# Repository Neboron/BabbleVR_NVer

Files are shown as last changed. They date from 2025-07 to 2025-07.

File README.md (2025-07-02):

# Face Tracker Hardware Design 

An open-source hardware project for building compact face tracker based on [Babble Project](https://babble.diy/).

## 🔧 Overview

Electronics design made with Altium Designer, including schematics, layout, and manufacturing files (Gerbers, CPL, BOM). Mechanical parts designed in SolidWorks.

## 📦 Features

- Modular and compact design
- Increased power efficiency
- Could be used both in wireless and USB mode

## 🖼️ Gallery

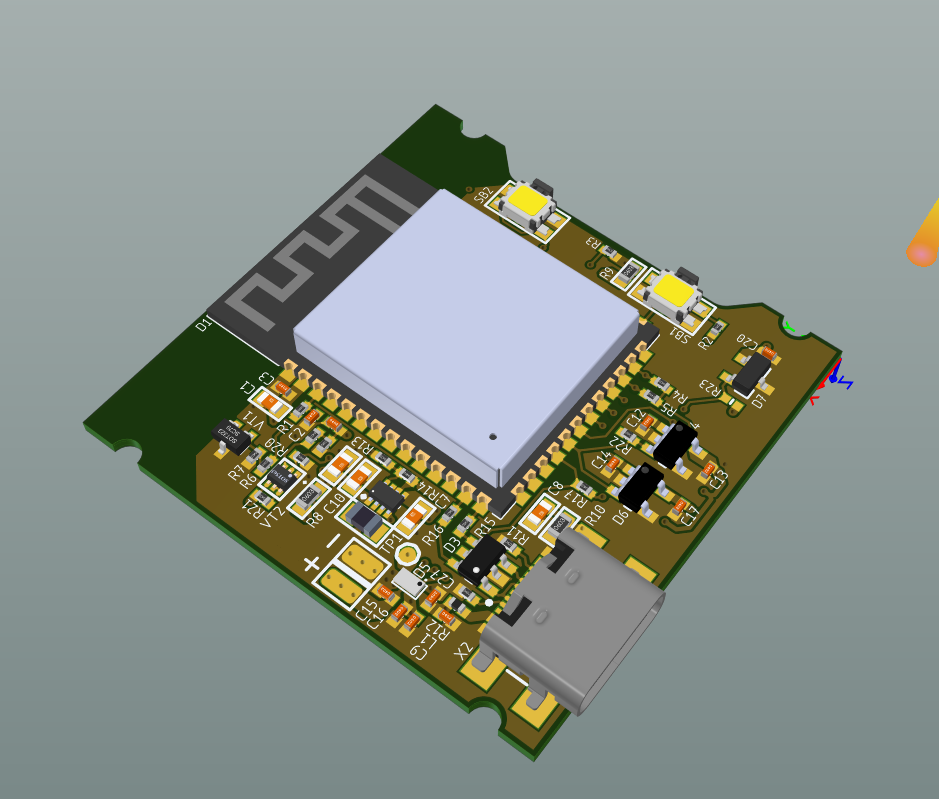
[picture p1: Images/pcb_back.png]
PCB Back

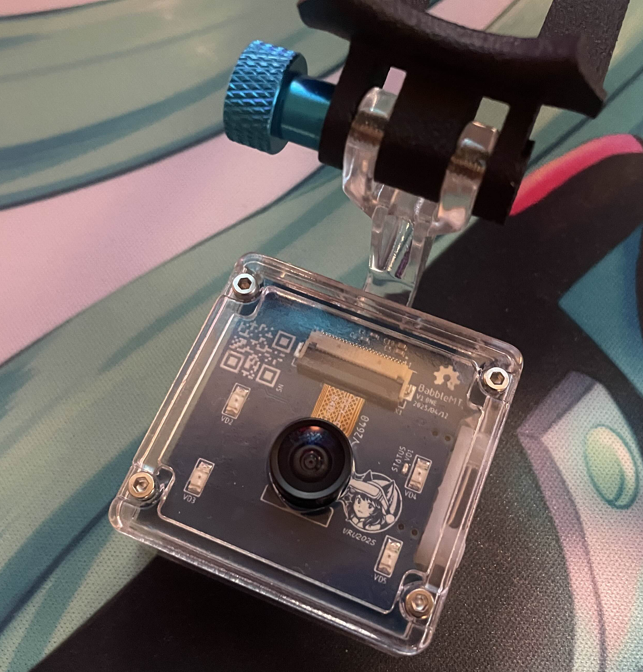
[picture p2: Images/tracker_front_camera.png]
Assembled Unit

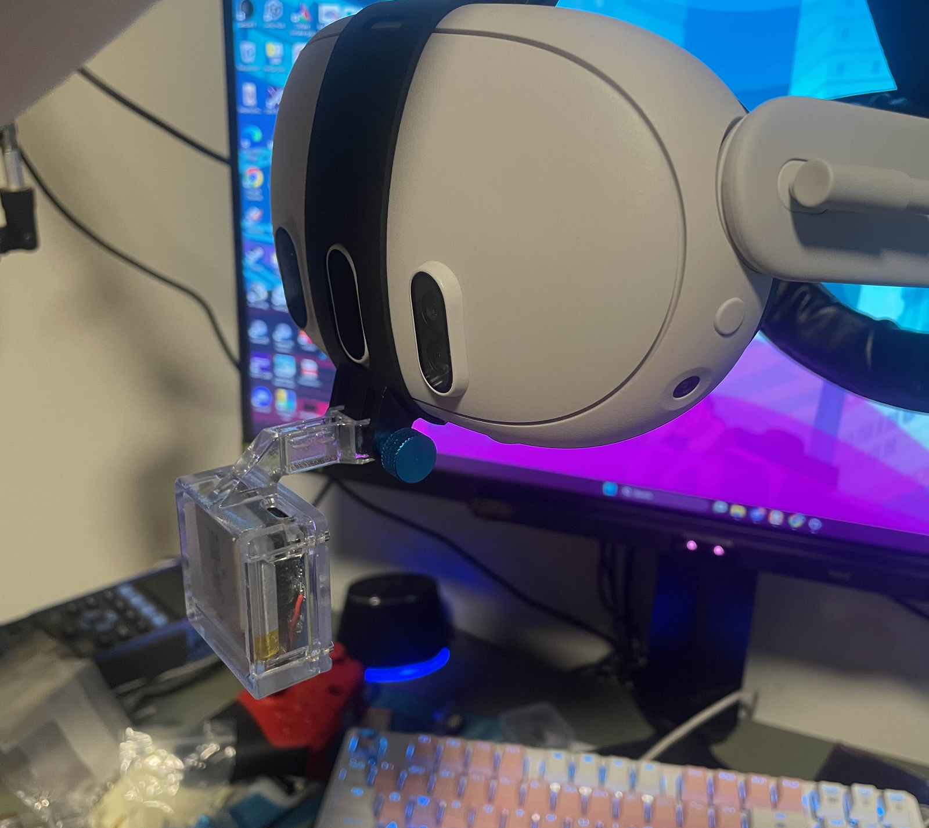
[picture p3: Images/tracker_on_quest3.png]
Tracker on Quest 3


Assembly guides will be added soon...

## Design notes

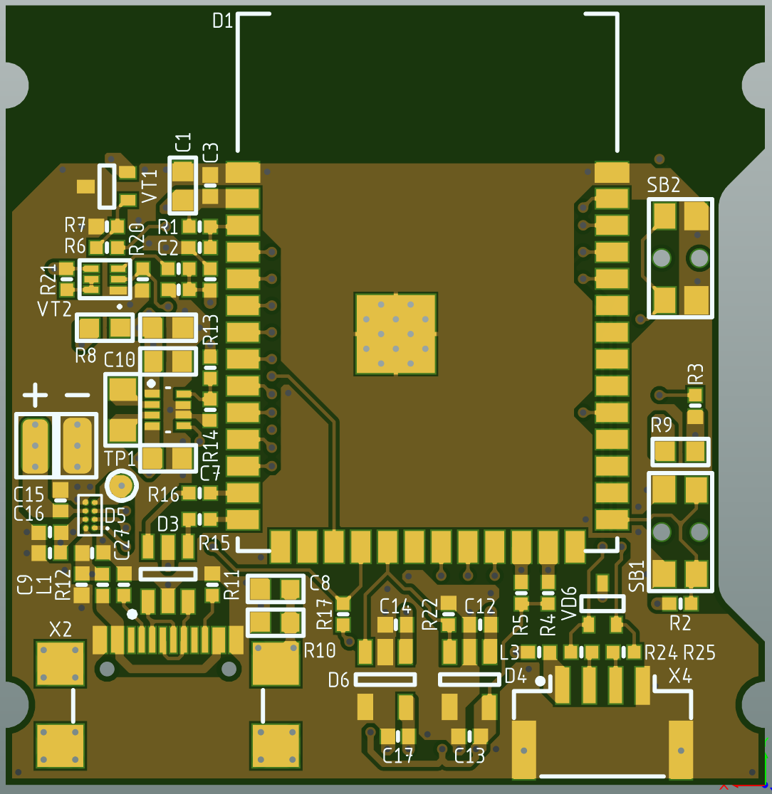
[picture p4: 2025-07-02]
Mechanical/Design/PCB/BottomSide2.png

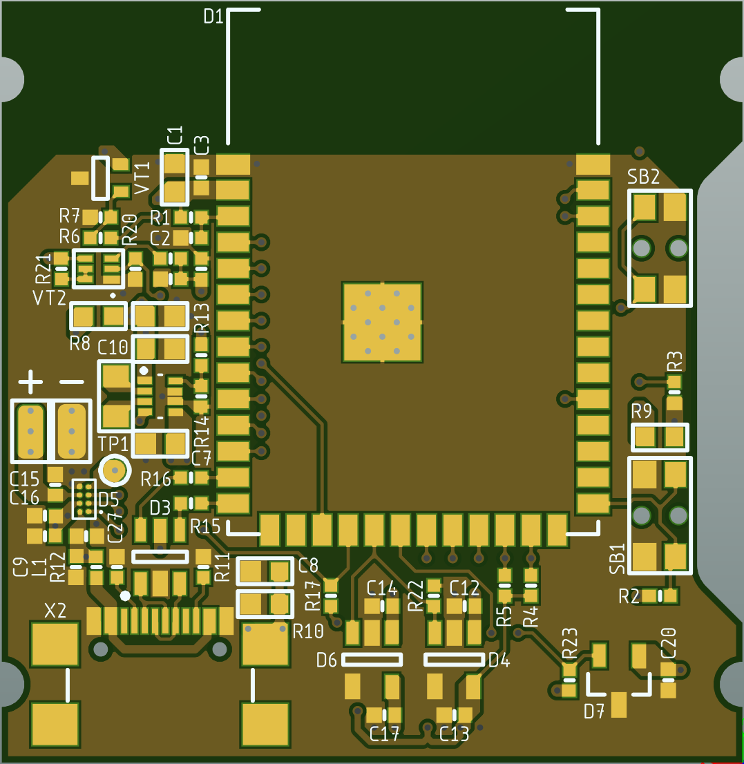
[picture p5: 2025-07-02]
Mechanical/Design/PCB/BottomSide.png

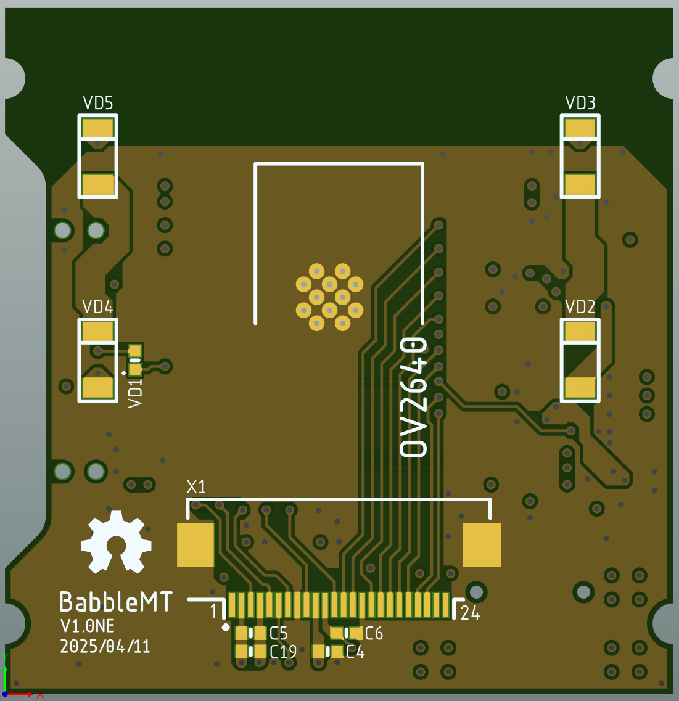
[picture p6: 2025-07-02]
Mechanical/Design/PCB/TopSide2.png

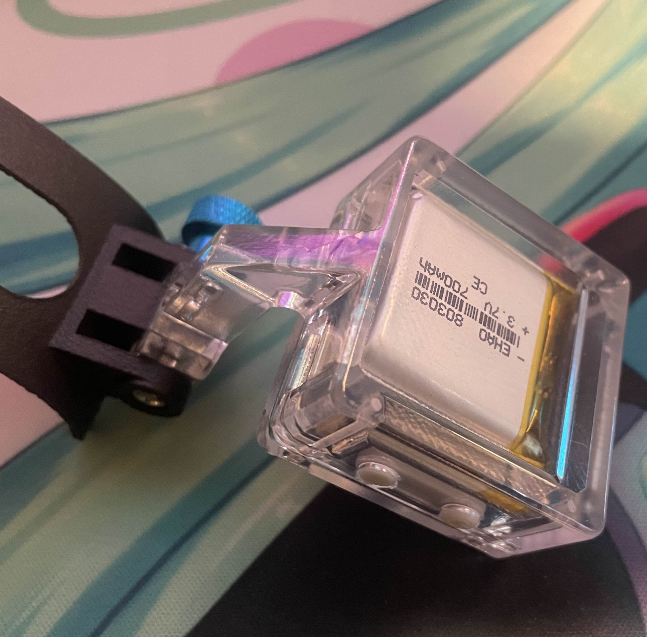
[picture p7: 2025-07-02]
Images/tracker_back.jpg

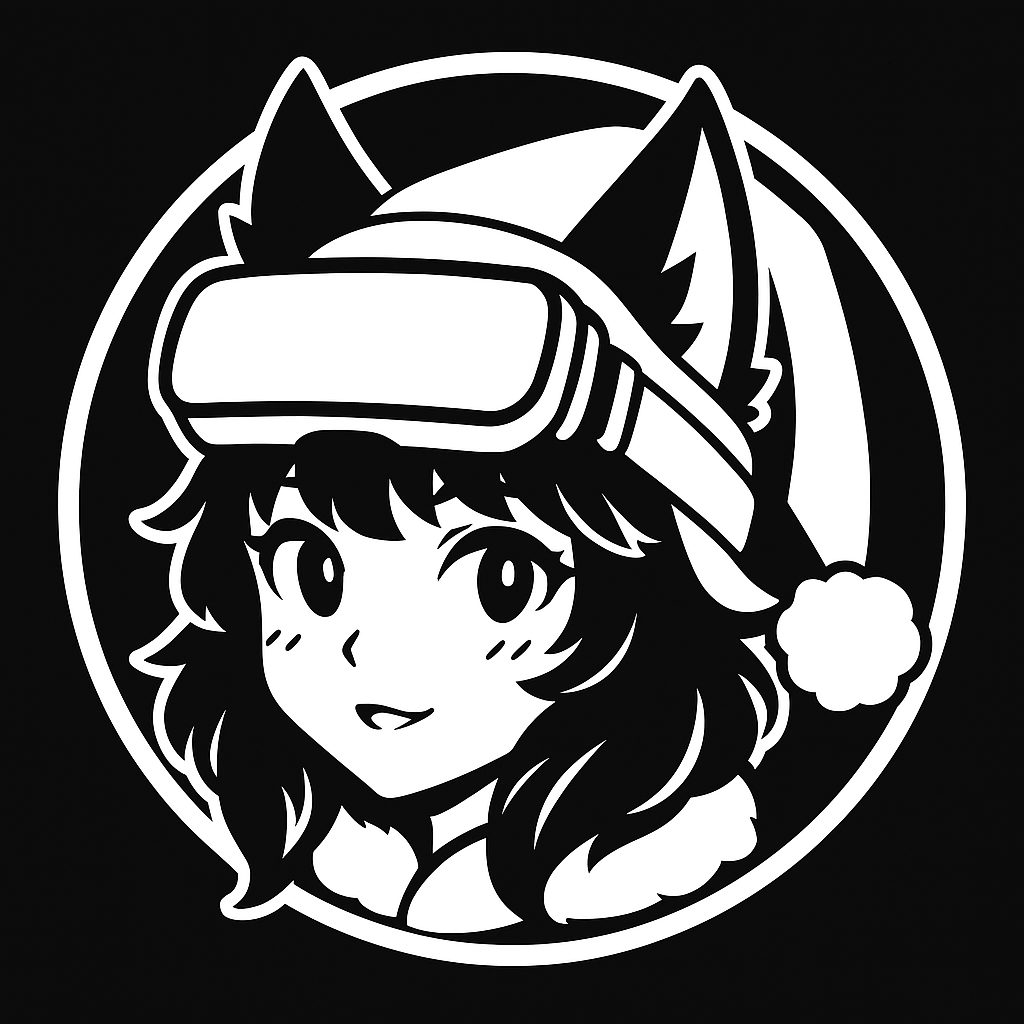
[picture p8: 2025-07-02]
PCB/Images/VRUkraine.png

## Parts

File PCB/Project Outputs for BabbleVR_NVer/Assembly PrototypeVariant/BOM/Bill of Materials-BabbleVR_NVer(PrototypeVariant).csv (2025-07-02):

Comment | Description | Designator | Footprint | LibRef | Quantity | PartNumber
Ceramic capacitor, 22uF, X5R, ±10%, 6.3V, 0603, -55...+125°C |  | C1, C7, C10, C11 | CAP: 0603 | Ceramic_0603 | 4
Ceramic capacitor, 1uF, X7R, ±10%, 6.3V, 0402, -55...+125°C |  | C2 | CAP: 0402 | Ceramic_0402 | 1
Ceramic capacitor, 100nF, X7R, ±10%, 16V, 0402, -55...+125°C |  | C3, C9, C18 | CAP: 0402 | Ceramic_0402 | 3
Ceramic capacitor, 4.7uF, X7R, ±10%, 16V, 0402, -55...+125°C |  | C4, C5, C6, C19 | CAP: 0402 | Ceramic_0402 | 4
Ceramic capacitor, 0.1uF, X7R, ±10%, 16V, 0603, -55...+125°C |  | C8 | CAP: 0603 | Ceramic_0603 | 1
Ceramic capacitor, 1uF, X7R, ±10%, 16V, 0402, -55...+125°C |  | C12, C13, C14, C15, C16, C17, C27, C33 | CAP: 0402 | Ceramic_0402 | 8
Wi-Fi module, WiFi 802.11 b/g/n (802.11n up to 150 Mbps) / Bluetooth v4.2 BR/EDR and BLE specification, 32 bit, SD card, UART, SPI, SDIO, I2C, LED PWM, Motor PWM, I2S, IR, pulse counter, GPIO, capacitive touch sensor, ADC, DAC, -40...+85°C, 18x25.5x3.1 | Wi-Fi | D1 | MOD: ESP32-S3-WROOM-1 | ESP32-S3-WROOM-1-N8R8 | 1 | ESP32-S3-WROOM-1-N8R8
DC/DC buck-boost converter, 1.6...5.5V, 2.4MHz, 1.2...5.3V, 1.5A, -40...+125°C, SOT-583 | Buck-boost converter | D2 | SOT583-8 | TPS631000DRLR | 1 | TPS631000DRLR
ESD protection, , 8kV, , -40...+125°C, SOT23-6L | ESD protection | D3 | SOT23-6 | USBLC6-2 | 1 | USBLC6-2
Linear voltage regulator, 2.9...6V, 0.5V, 1.5V, 0.25A, -40...+85°C, SOT23-5 | Linear voltage regulator 2.8V | D4 | SOT23-5 | AP2139AK-2.8TRG1 | 1 | AP2139AK-2.8TRG1
Charger li-ion battery, input 4.35...26V, , 1A, -40...+125°C, 8-DSBGA | Charger | D5 | 8-DSBGA | BQ25180YBGR | 1 | BQ25180YBGR
Linear voltage regulator, 2...5.5V, 0.26V, 1.2V, 0.3A, -40...+85°C, SOT23-5 | Linear voltage regulator 1.2V | D6 | SOT23-5 | TLV70212DBVR | 1 | TLV70212DBVR
Fixed inductor, BEAD, ±25%, 0402, 900mA, -55...+125°C |  | L1, L3 | IND: 0402 | Inductor_0402 | 2 | BLM15PX601SN1D
Fixed inductor, 1µH, ±20%, 0805, 2.2A, -55...+125°C |  | L2 | IND: 0805 | Inductor_0805 | 1 | MAKK2016T1R0M
Resistor film, 10k, ±5%, 0402, 0.063W, -55...+125°C |  | R1, R2, R4, R5, R7, R17, R19, R22 | RES: 0402 | Resistor_0402 | 8
Resistor film, 470R, ±5%, 0402, 0.063W, -55...+125°C |  | R3, R24, R25 | RES: 0402 | Resistor_0402 | 3 | RC0402JR-07100RL
Resistor film, 22R, ±5%, 0402, 0.063W, -55...+125°C |  | R6, R15, R16 | RES: 0402 | Resistor_0402 | 3
Resistor film, 9.1R, ±5%, 0603, 0.1W, -55...+125°C |  | R8, R9 | RES: 0603 | Resistor_0603 | 2
Resistor film, 330R, ±5%, 0603, 0.1W, -55...+125°C |  | R10 | RES: 0603 | Resistor_0603 | 1
Resistor film, 5.1k, ±5%, 0402, 0.063W, -55...+125°C |  | R11, R12, R18 | RES: 0402 | Resistor_0402 | 3
Resistor film, 510k, ±5%, 0402, 0.063W, -55...+125°C |  | R13, R20, R21 | RES: 0402 | Resistor_0402 | 3
Resistor film, 91k, ±5%, 0402, 0.063W, -55...+125°C |  | R14 | RES: 0402 | Resistor_0402 | 1
Tactile button, TS-1186F |  | SB1, SB2 | BUT: TS-1186F-B-A | Button_tactile | 2 | TS-1186F-C-A
Test point, Keystone, 5001 |  | TP1 | CON: TEST POINT 1 MM | Connector_Test_Point | 1 | 5001
LED, Green, *, *, *, -55...+150°C |  | VD1 | LED: 0402R | LED_single | 1
LED, 850...858nm, 35mA, 1.5V, 1206, -55...+150°C |  | VD2, VD3, VD4, VD5 | LED: 1206R | LED_single | 4 | XL-3216HIRC-850
TVS, 5.5V, 2A, , , SC-70-3, -55...+150°C |  | VD6 | SC-70 | TVS_array | 1 | SP1001-02JTG
MOSFET N-channel transistor, 60V, 380mA, , 300mW, 2.3Ohm, 34pF, SC-70, -55...+150°C |  | VT1 | SC-70 | MOSFET_N_123 | 1 | L2N7002KWT1G
MOSFET Dula-channel transistor, 20V, 700mA, N-70pC, P-850pC, 1W, N-480mOhm, P-970mOhm, N-750pF, P-1000pF, SOT563, -55...+150°C |  | VT2 | SOT563-6 | MOSFET_DUAL_NP_ISO | 1 | DMC2400UV
Connector, 24pin, 0.5mm, FFC/FPC, 0.5A |  | X1 | CON: FFC/FPC-24-0.5(Hirose) | Connector_FFC_24 (TF31-24S-0.5SH(800)) | 1 | TF31-24S-0.5SH(800)
USB Type C, 5A |  | X2 | CON: TYPE-C-SOFNG MC-311S | Connector_USB_Type_C | 1 | TYPEC-304YSSW-ACP16
Connector, 2pin, 2mm, , |  | X3 | CON: BAT (2.00) | Connector_BAT-2 | 1
Connector, 4pin, 1.25mm, 50VDC, 1A |  | X4 | CON: SM04B-GHS | Connector_SM04B | 1 | SM04B-GHS

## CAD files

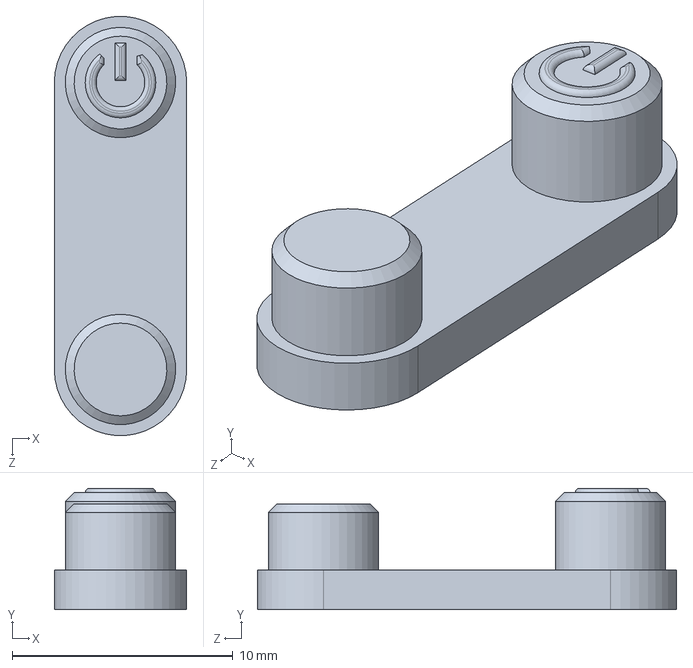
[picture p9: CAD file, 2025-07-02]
Mechanical/Design/ButtonCover_01.SLDPRT
6.00 x 5.50 x 19.0 mm

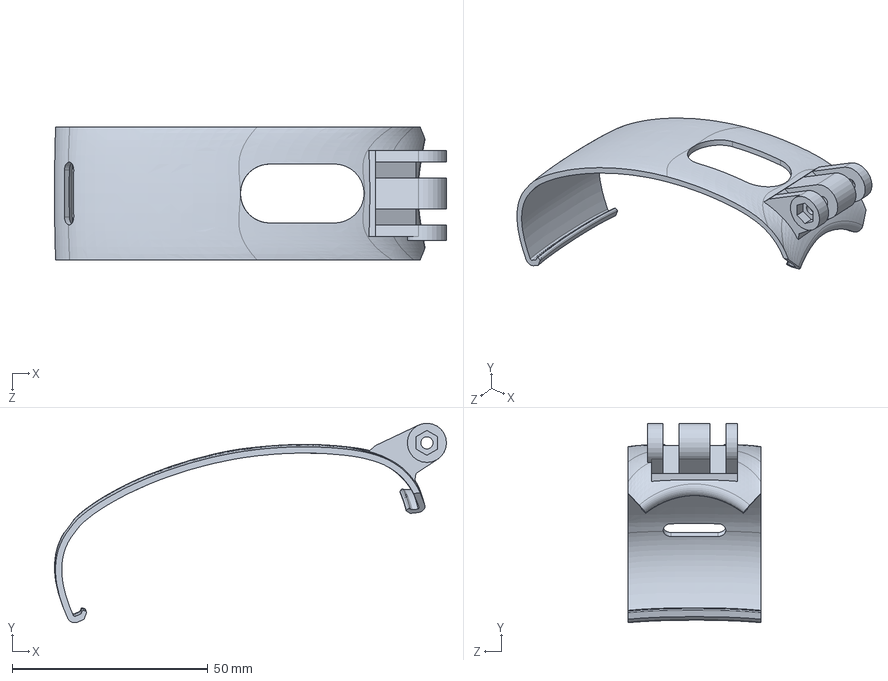
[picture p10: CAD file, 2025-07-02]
Mechanical/Design/Quest3/Quest3_MountScobe.SLDPRT
100.0 x 50.9 x 34.0 mm

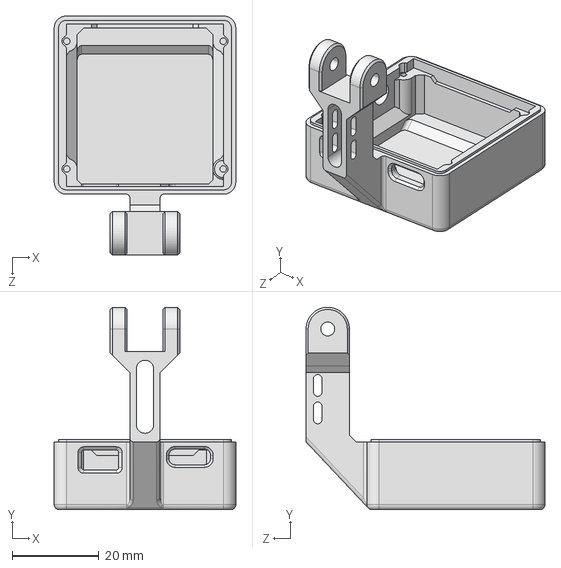
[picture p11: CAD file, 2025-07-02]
Mechanical/FabricationOutputs/STEP/CaseBottom_01.STEP
41.8 x 46.6 x 55.0 mm

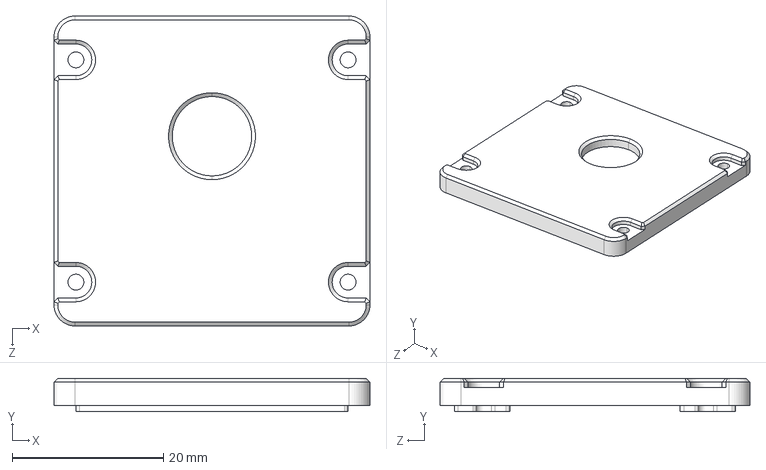
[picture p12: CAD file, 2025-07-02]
Mechanical/FabricationOutputs/STEP/CaseTop_01.STEP
41.8 x 4.40 x 41.0 mm

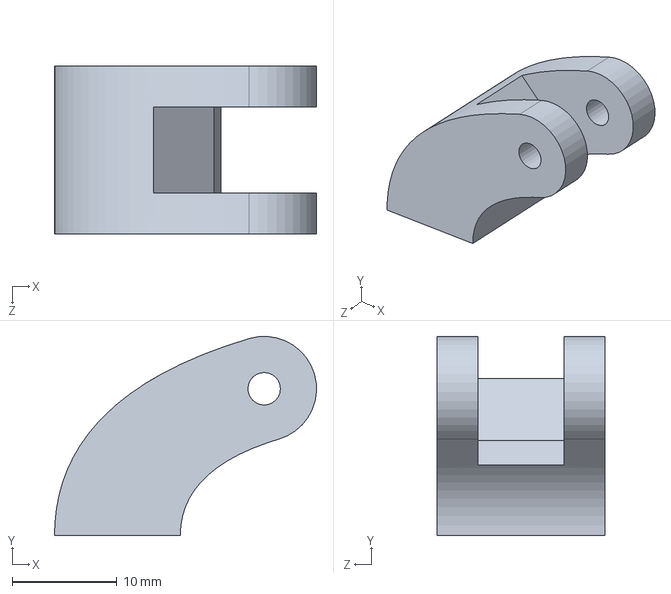
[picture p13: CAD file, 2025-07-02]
Mechanical/Design/TrackerHinge_01.SLDPRT
25.0 x 19.0 x 16.0 mm

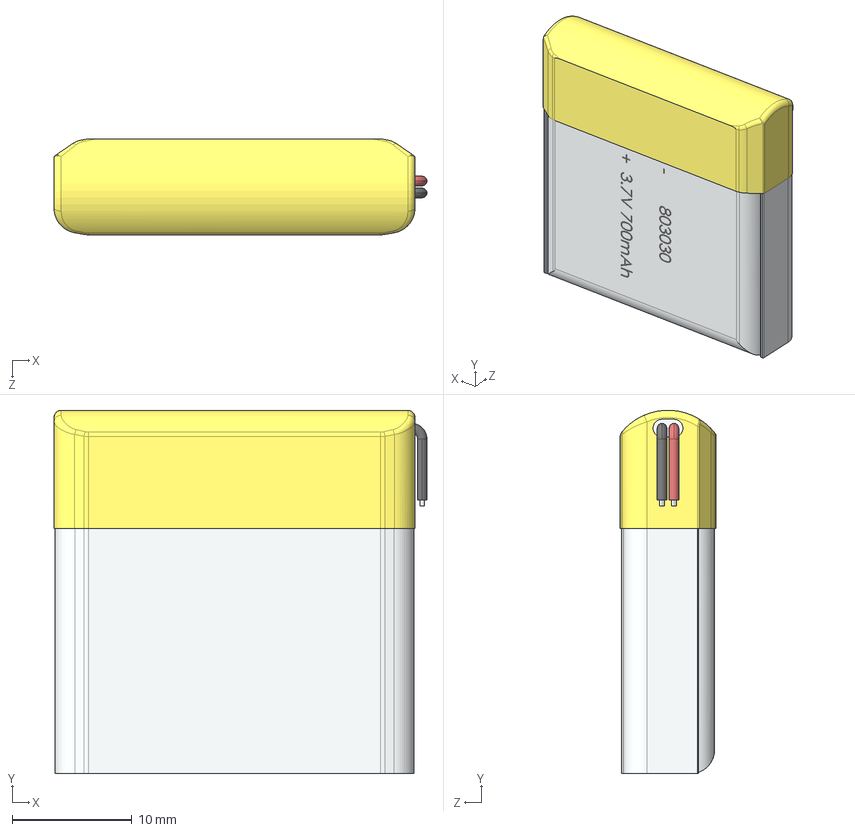
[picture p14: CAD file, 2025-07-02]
Mechanical/Design/Battery/803030.STEP
31.2 x 30.4 x 8.00 mm

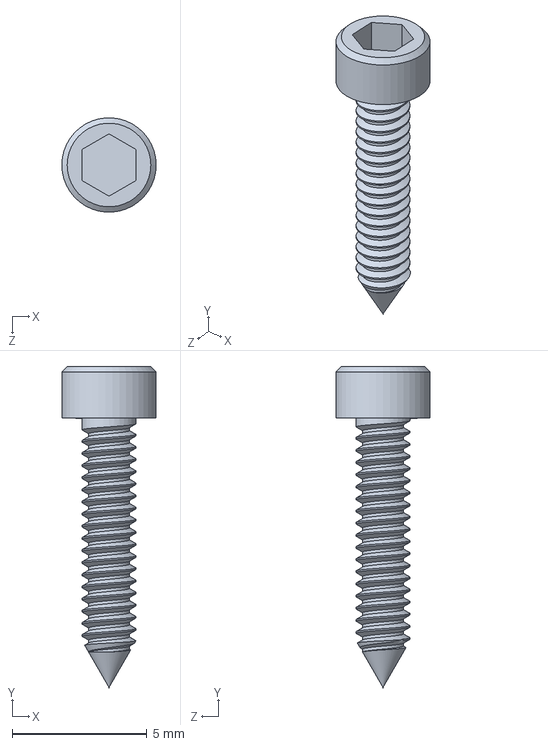
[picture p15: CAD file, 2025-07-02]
Mechanical/Design/M2_SelfTappingScrew.SLDPRT
3.50 x 11.9 x 3.49 mm

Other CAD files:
Mechanical/Design/CaseBottom_01.SLDPRT
Mechanical/FabricationOutputs/STEP/Quest3_MountScobe_01.STEP
Mechanical/Design/CaseTop_01.SLDPRT
Mechanical/FabricationOutputs/STEP/ButtonCover_01.STEP
Mechanical/Design/Battery/803030.SLDPRT

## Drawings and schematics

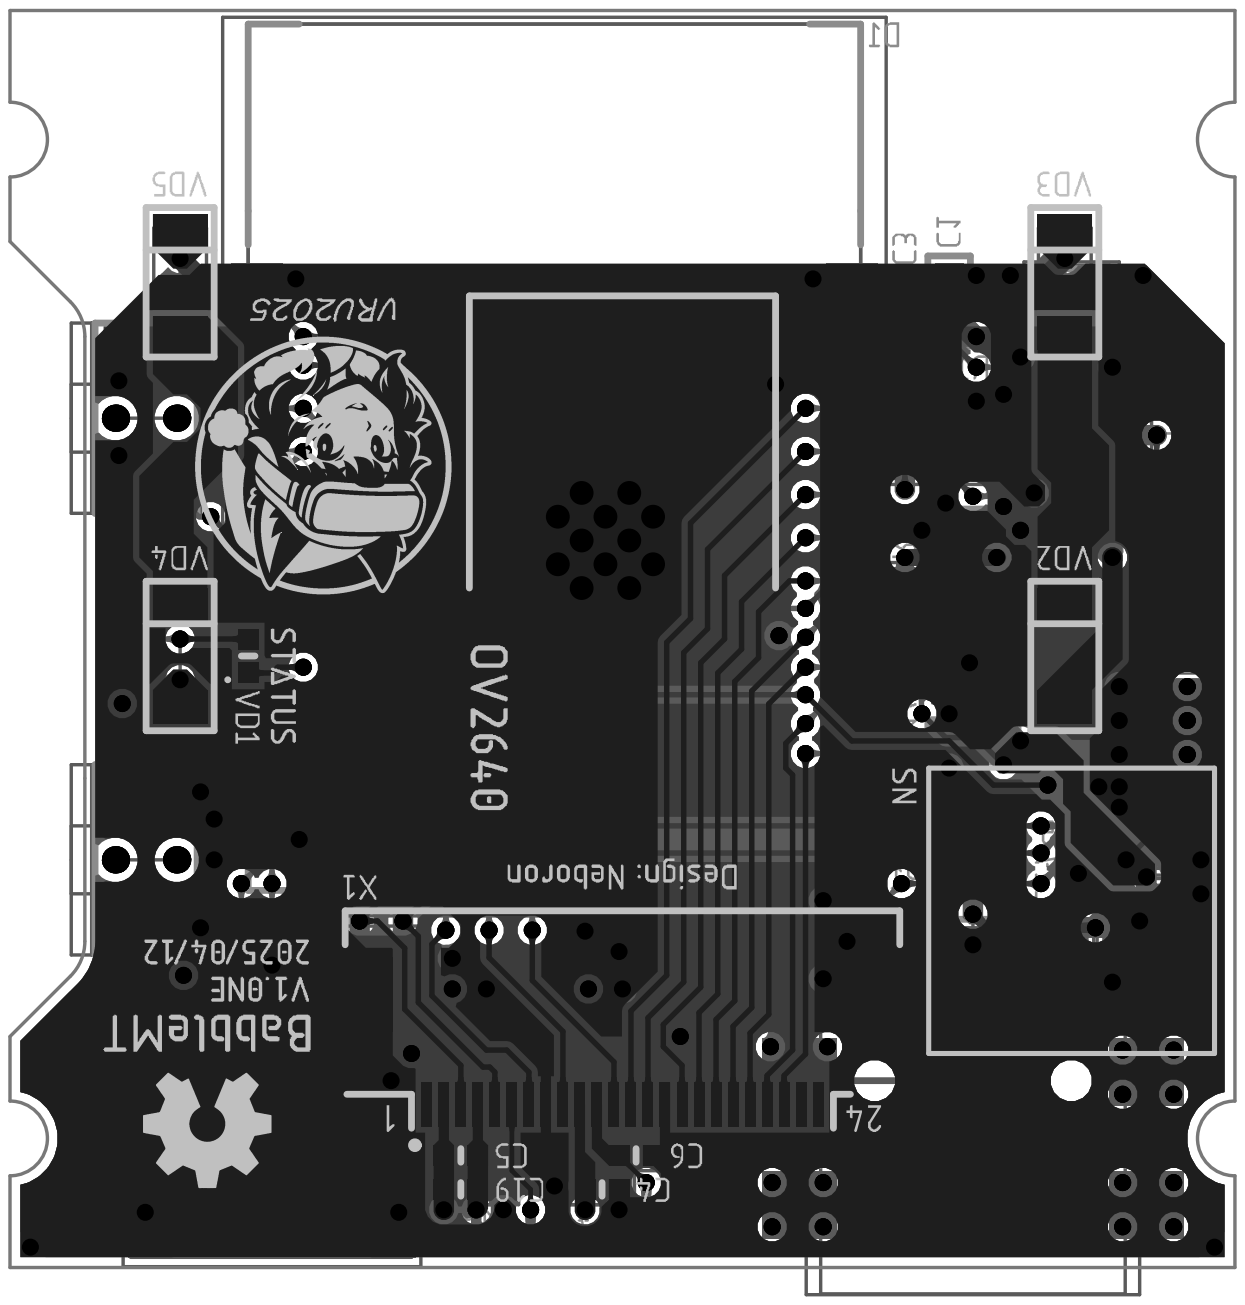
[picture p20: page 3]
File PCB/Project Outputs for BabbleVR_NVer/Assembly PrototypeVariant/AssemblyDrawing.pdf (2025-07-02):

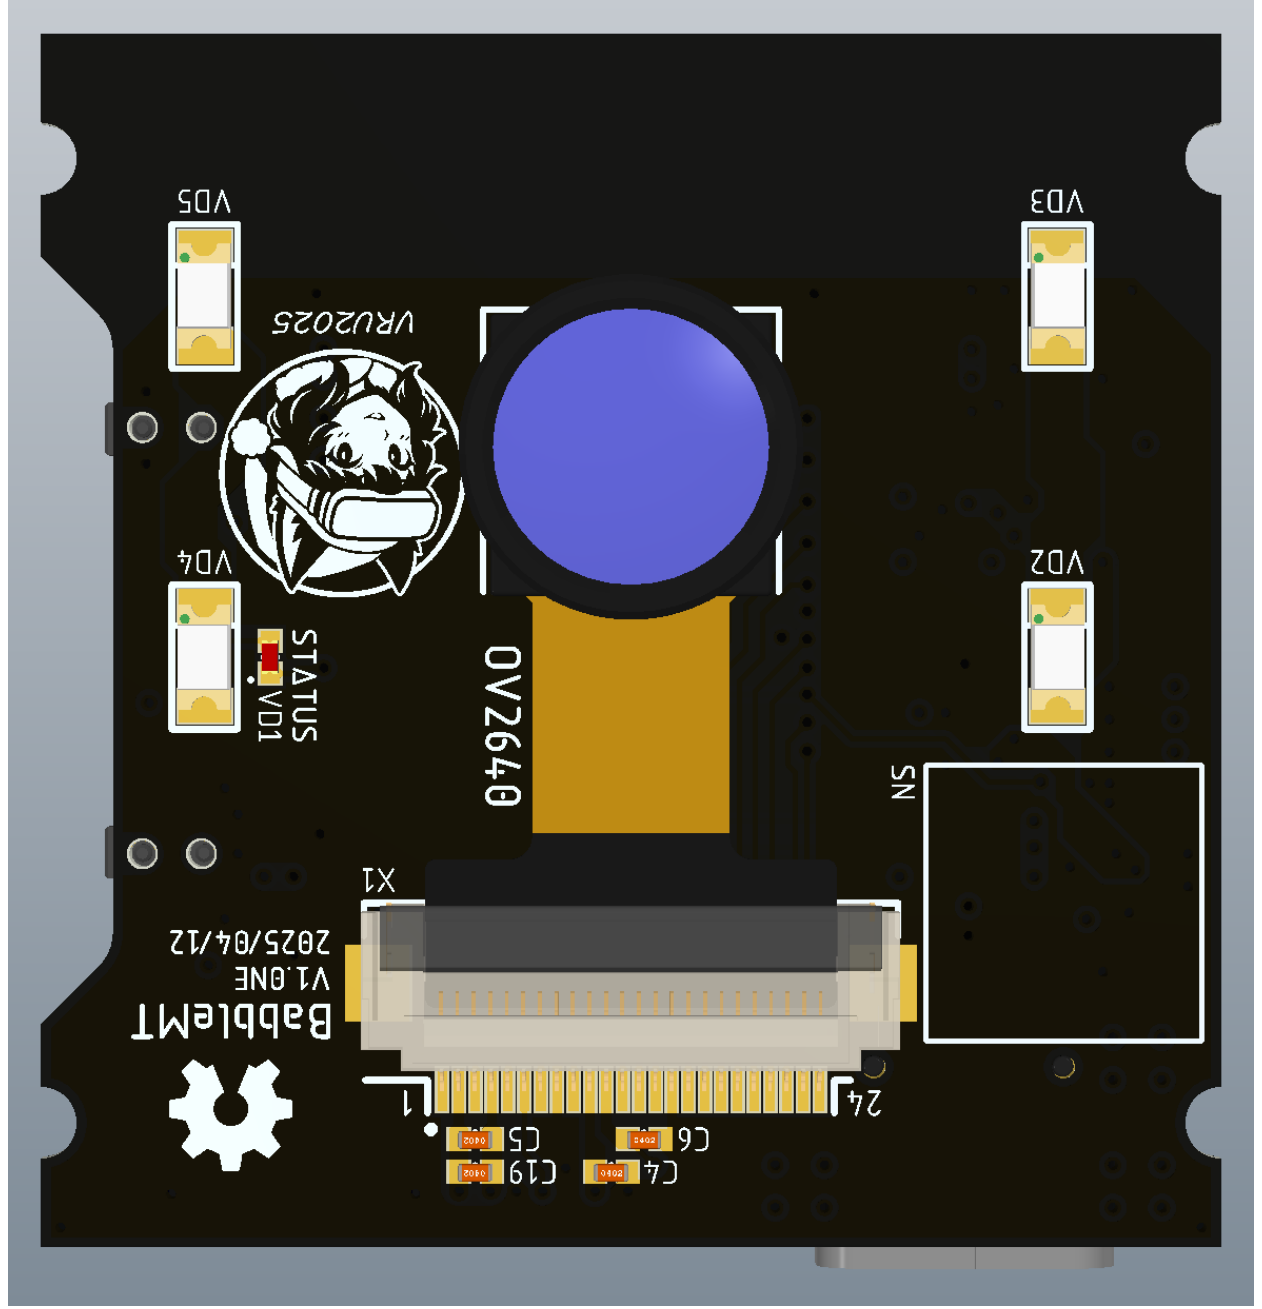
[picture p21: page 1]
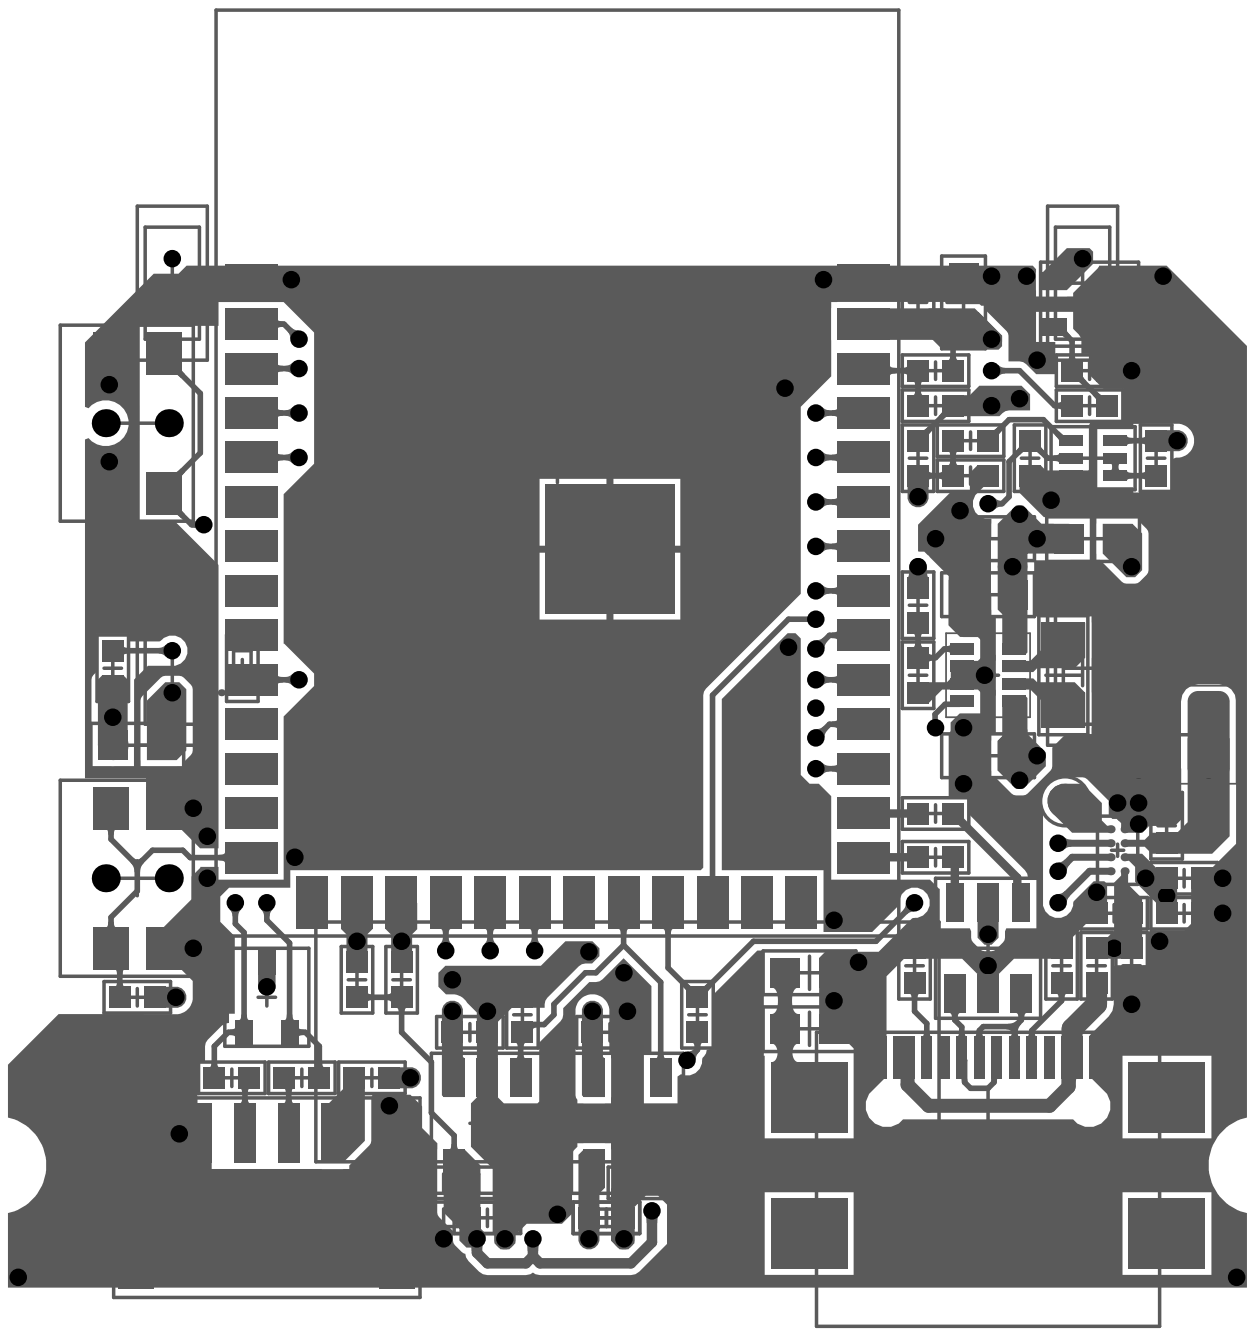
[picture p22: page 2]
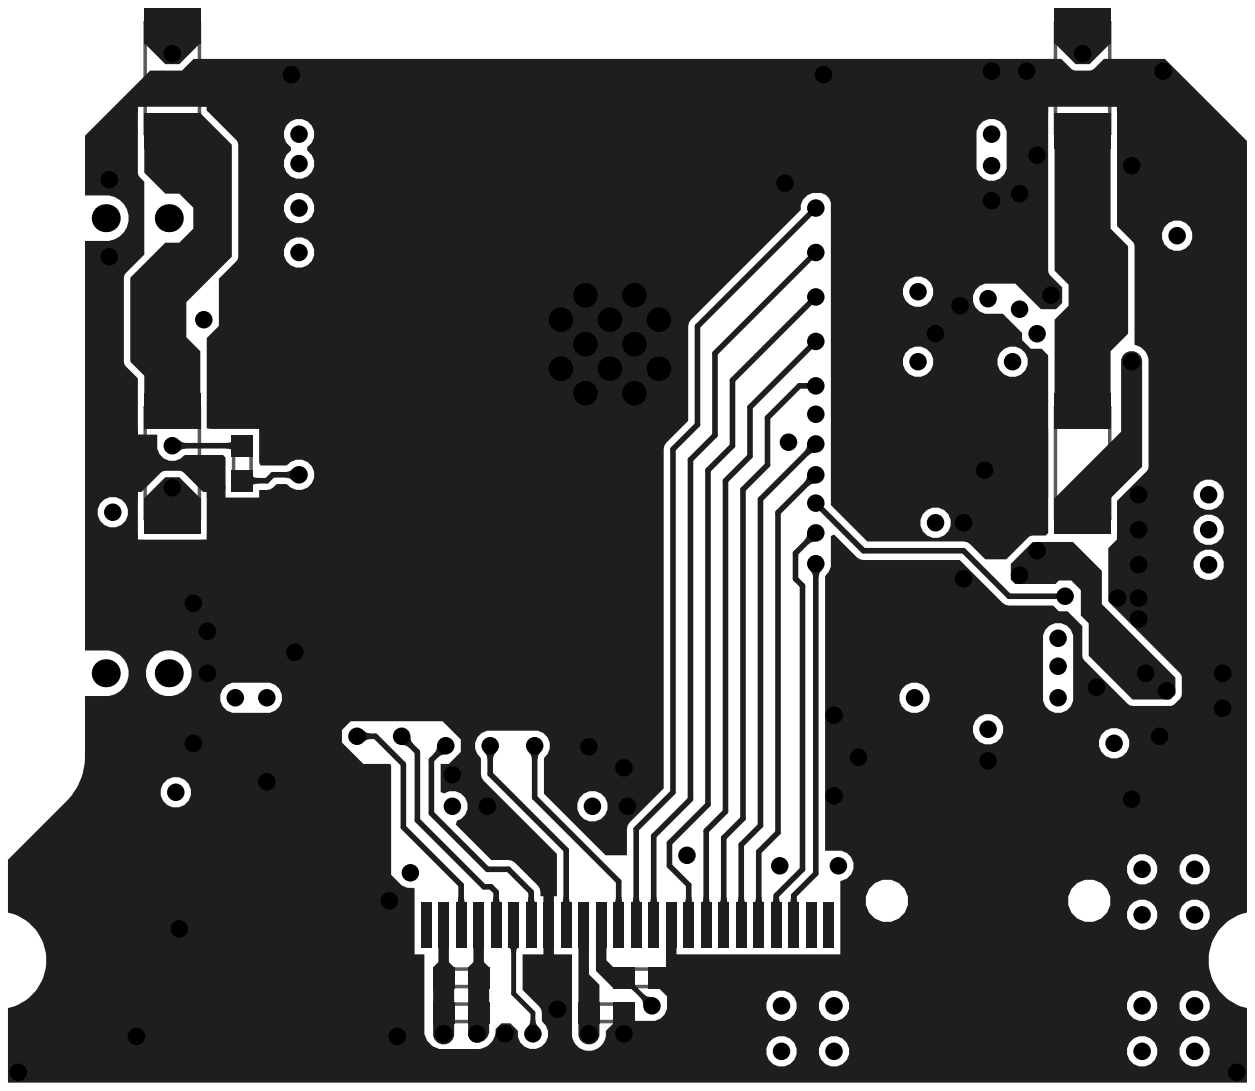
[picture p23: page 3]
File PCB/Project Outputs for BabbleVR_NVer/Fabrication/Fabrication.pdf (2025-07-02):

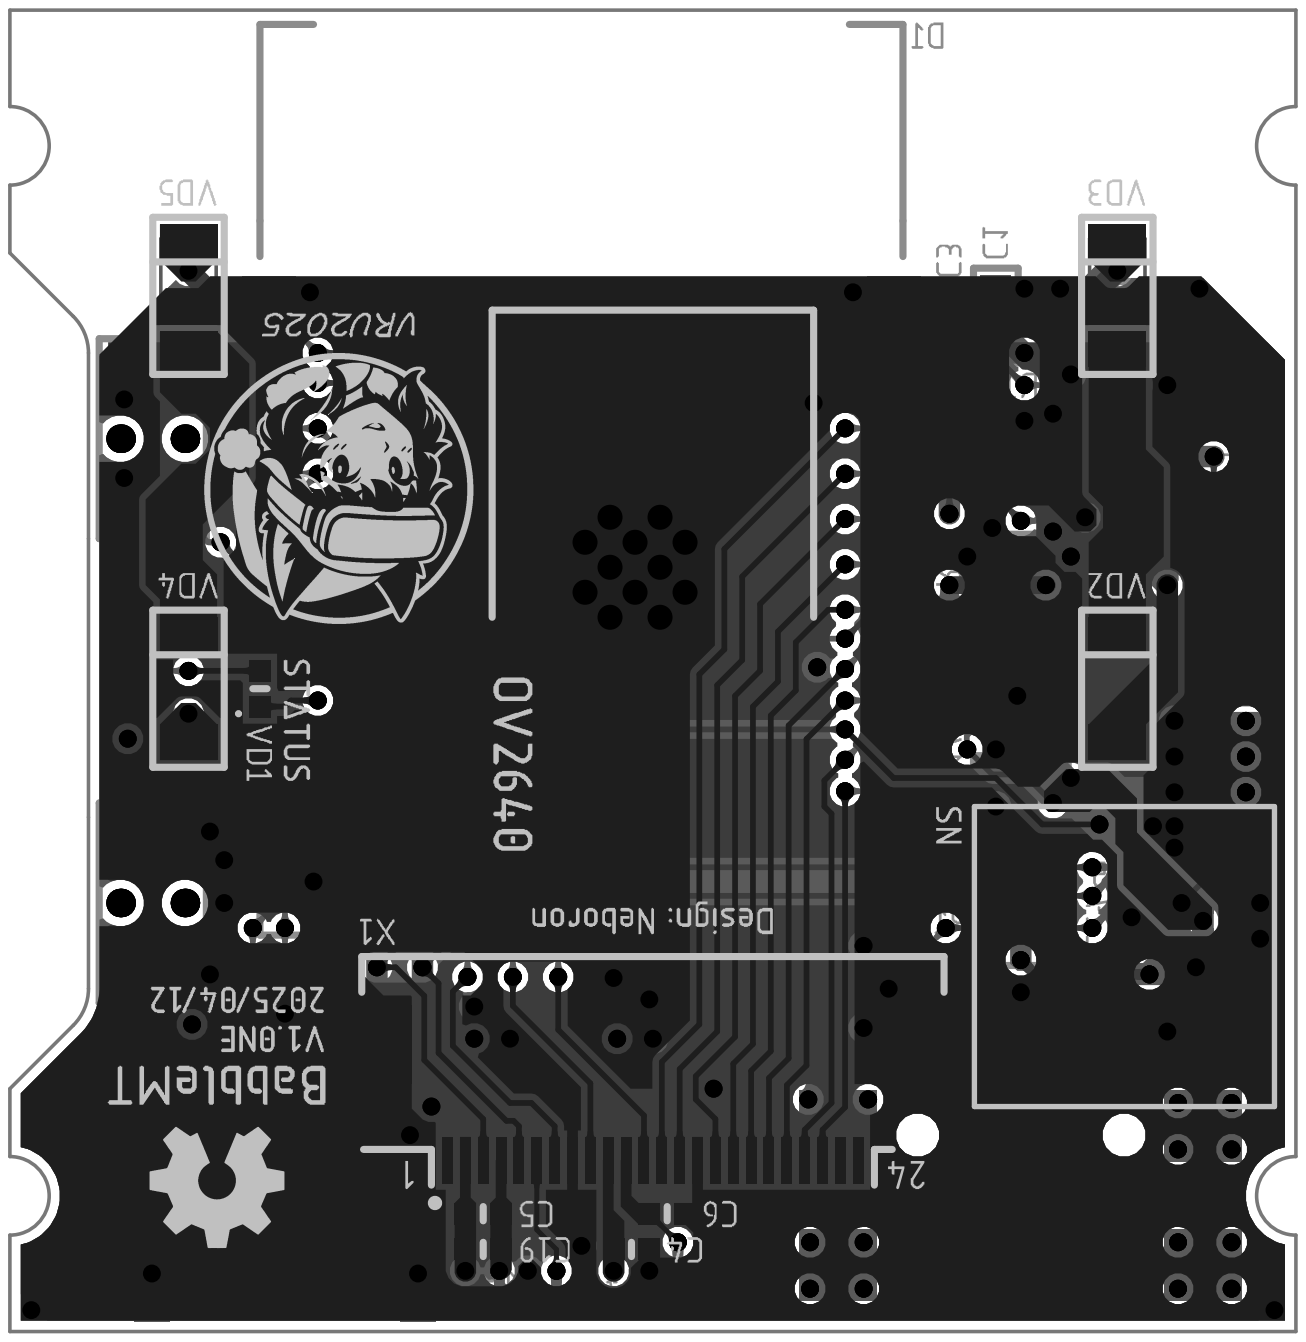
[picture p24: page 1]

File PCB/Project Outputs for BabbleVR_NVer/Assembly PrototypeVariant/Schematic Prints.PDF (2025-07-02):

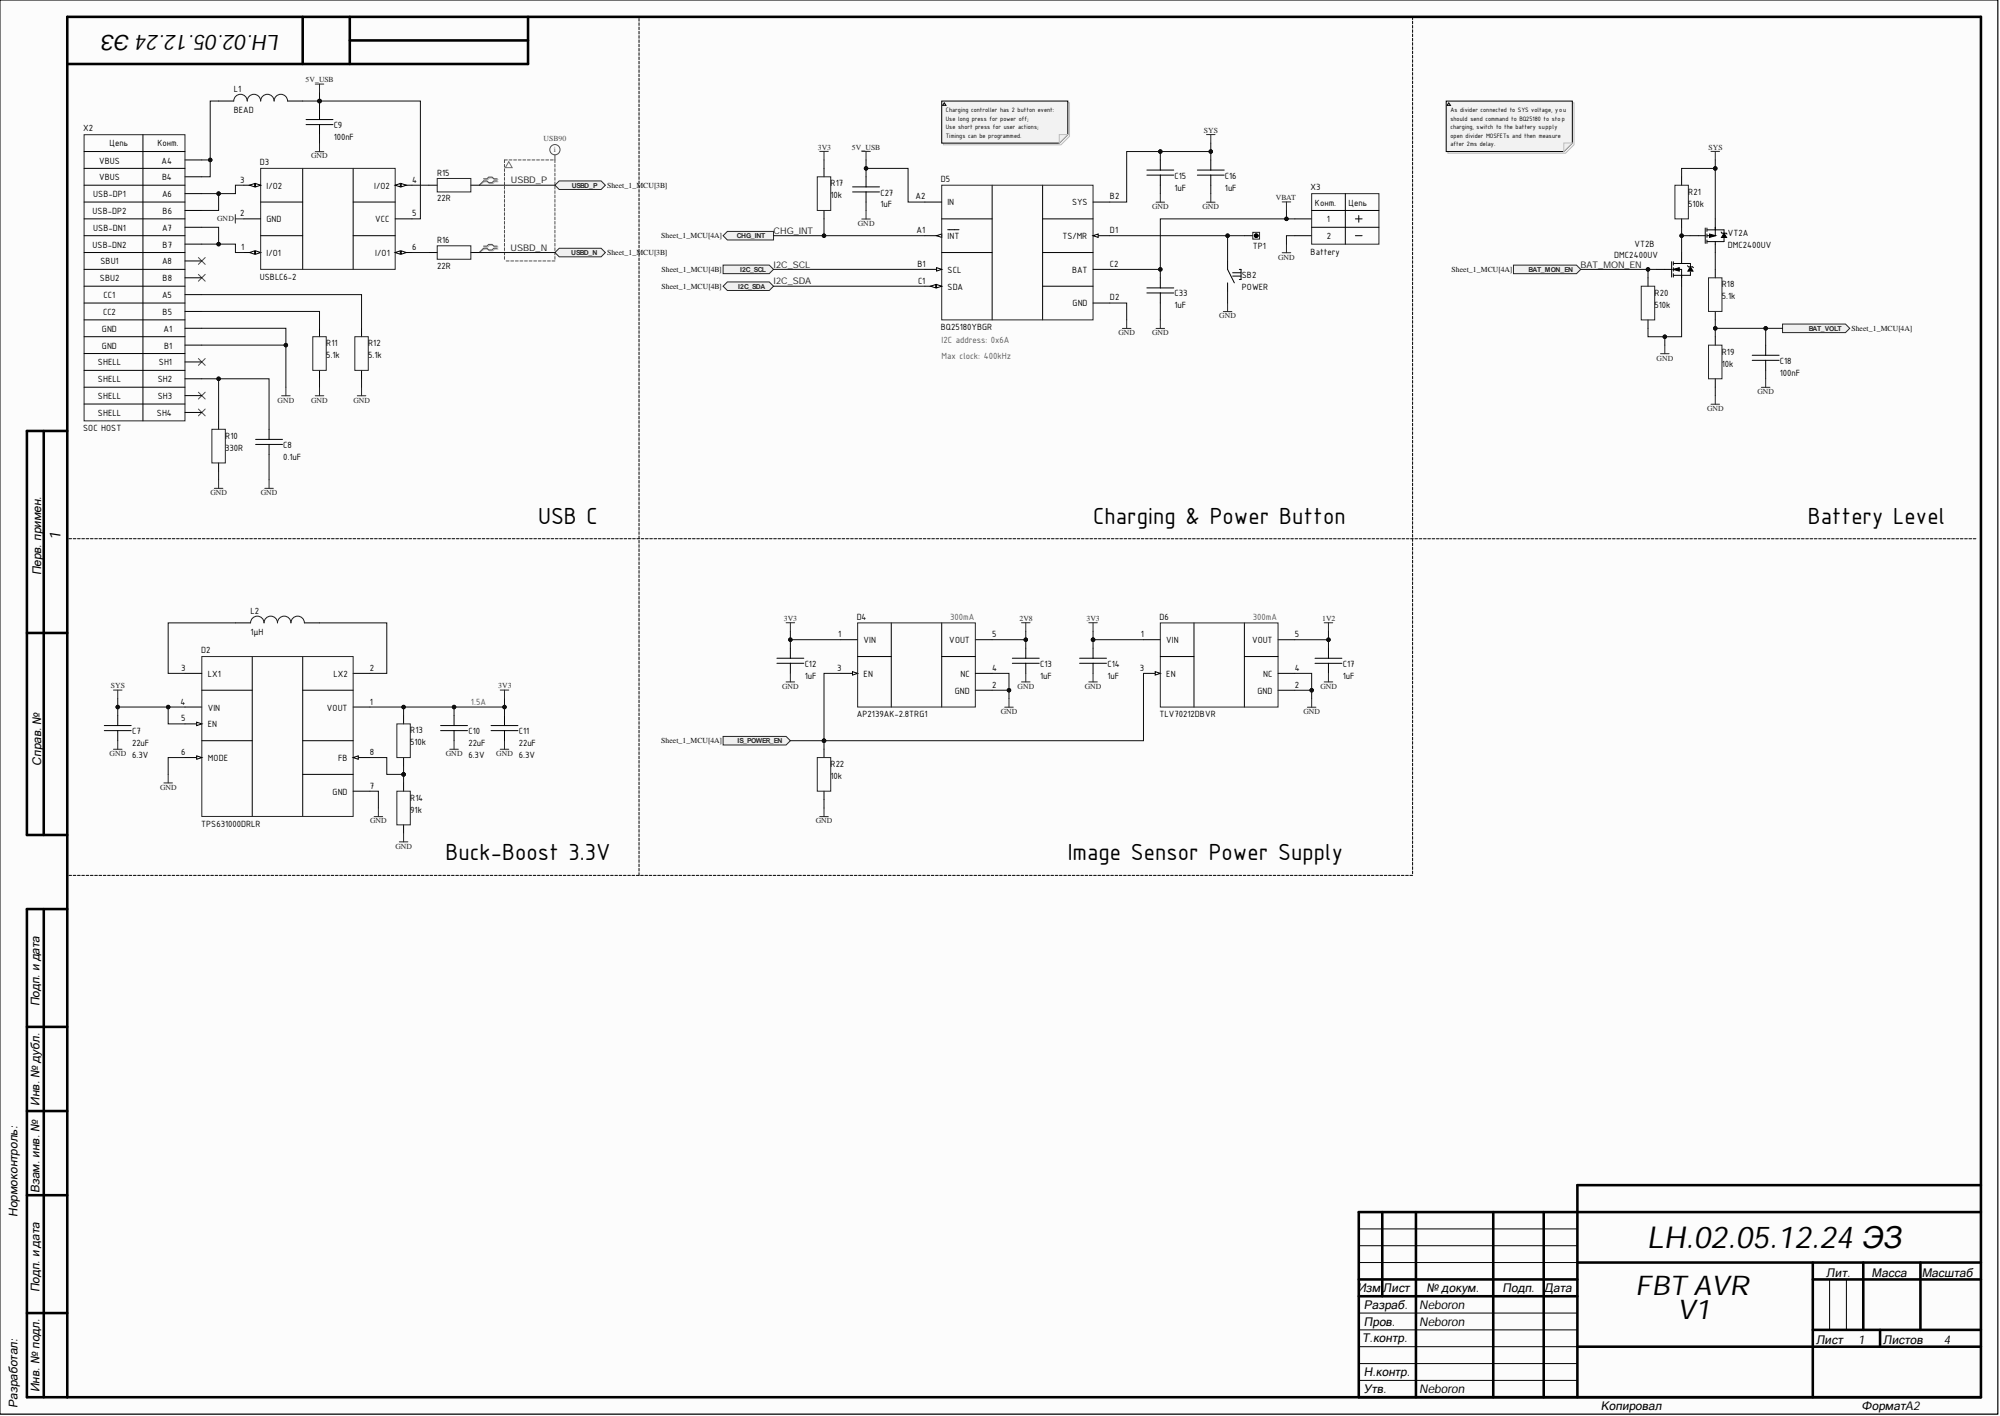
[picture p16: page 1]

Цепь | Конт .
VB U S | A4B4

S HELL | S H 1

S HELL | S H 2

S HELL | S H 3 | D

S HELL | S H 4

Инв. № подл. Инв. № дубл. Подп. и дата Взам. инв. № Подп. и дата Перв. примен. Справ. №

Image Sensor Power Supply

Изм | . Лист | № докум . | Подп . | Дата | | Лит. | Масса | Масштаб 1

FBT AVR V1

Разраб. | | Neboron
Пров. | | Neboron
Т.контр . | | | | | Лист | Листов 4

Утв. Н.контр .

Neboron

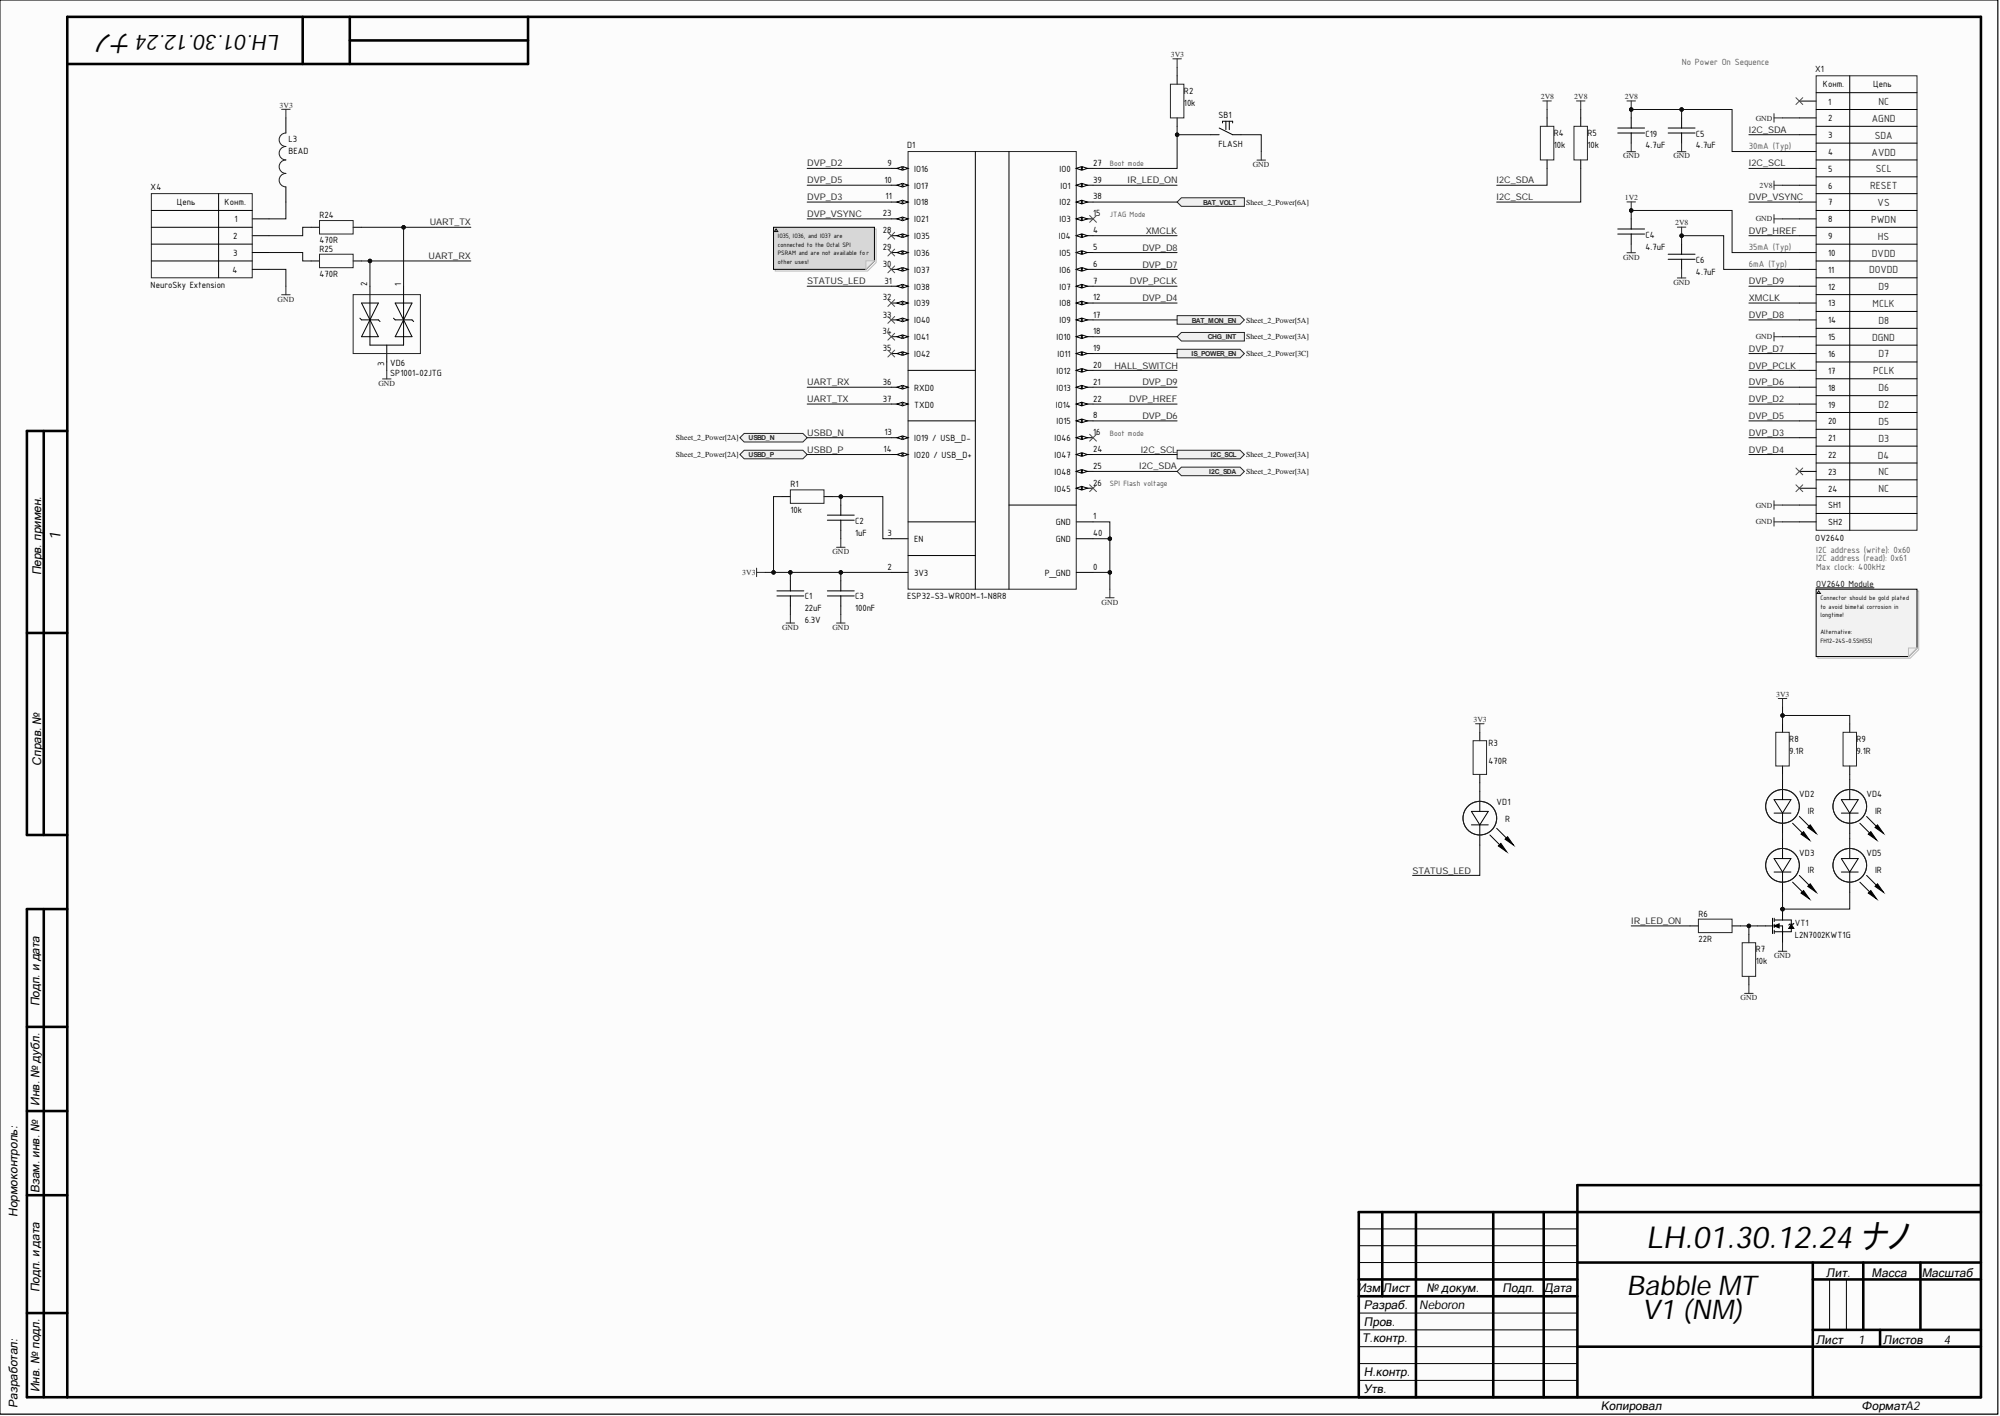
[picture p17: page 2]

No Power On Sequence

Конт . | Цепь

AVDD

RESE T

RAM and are not available

11 | DOVDD

15 | DGND

23 | NC
24SH | NC

Инв. № подл. Инв. № дубл. Подп. и дата Взам. инв. № Подп. и дата Перв. примен. Справ. №

tor should be gold plated

Изм | . Лист | № докум . | Подп . | Дата | | Лит. | Масса | Масштаб 1

Babble MT V1 (NM)

Разраб. | | Neboron
Пров.
Т.контр . | | | | | Лист | Листов 4

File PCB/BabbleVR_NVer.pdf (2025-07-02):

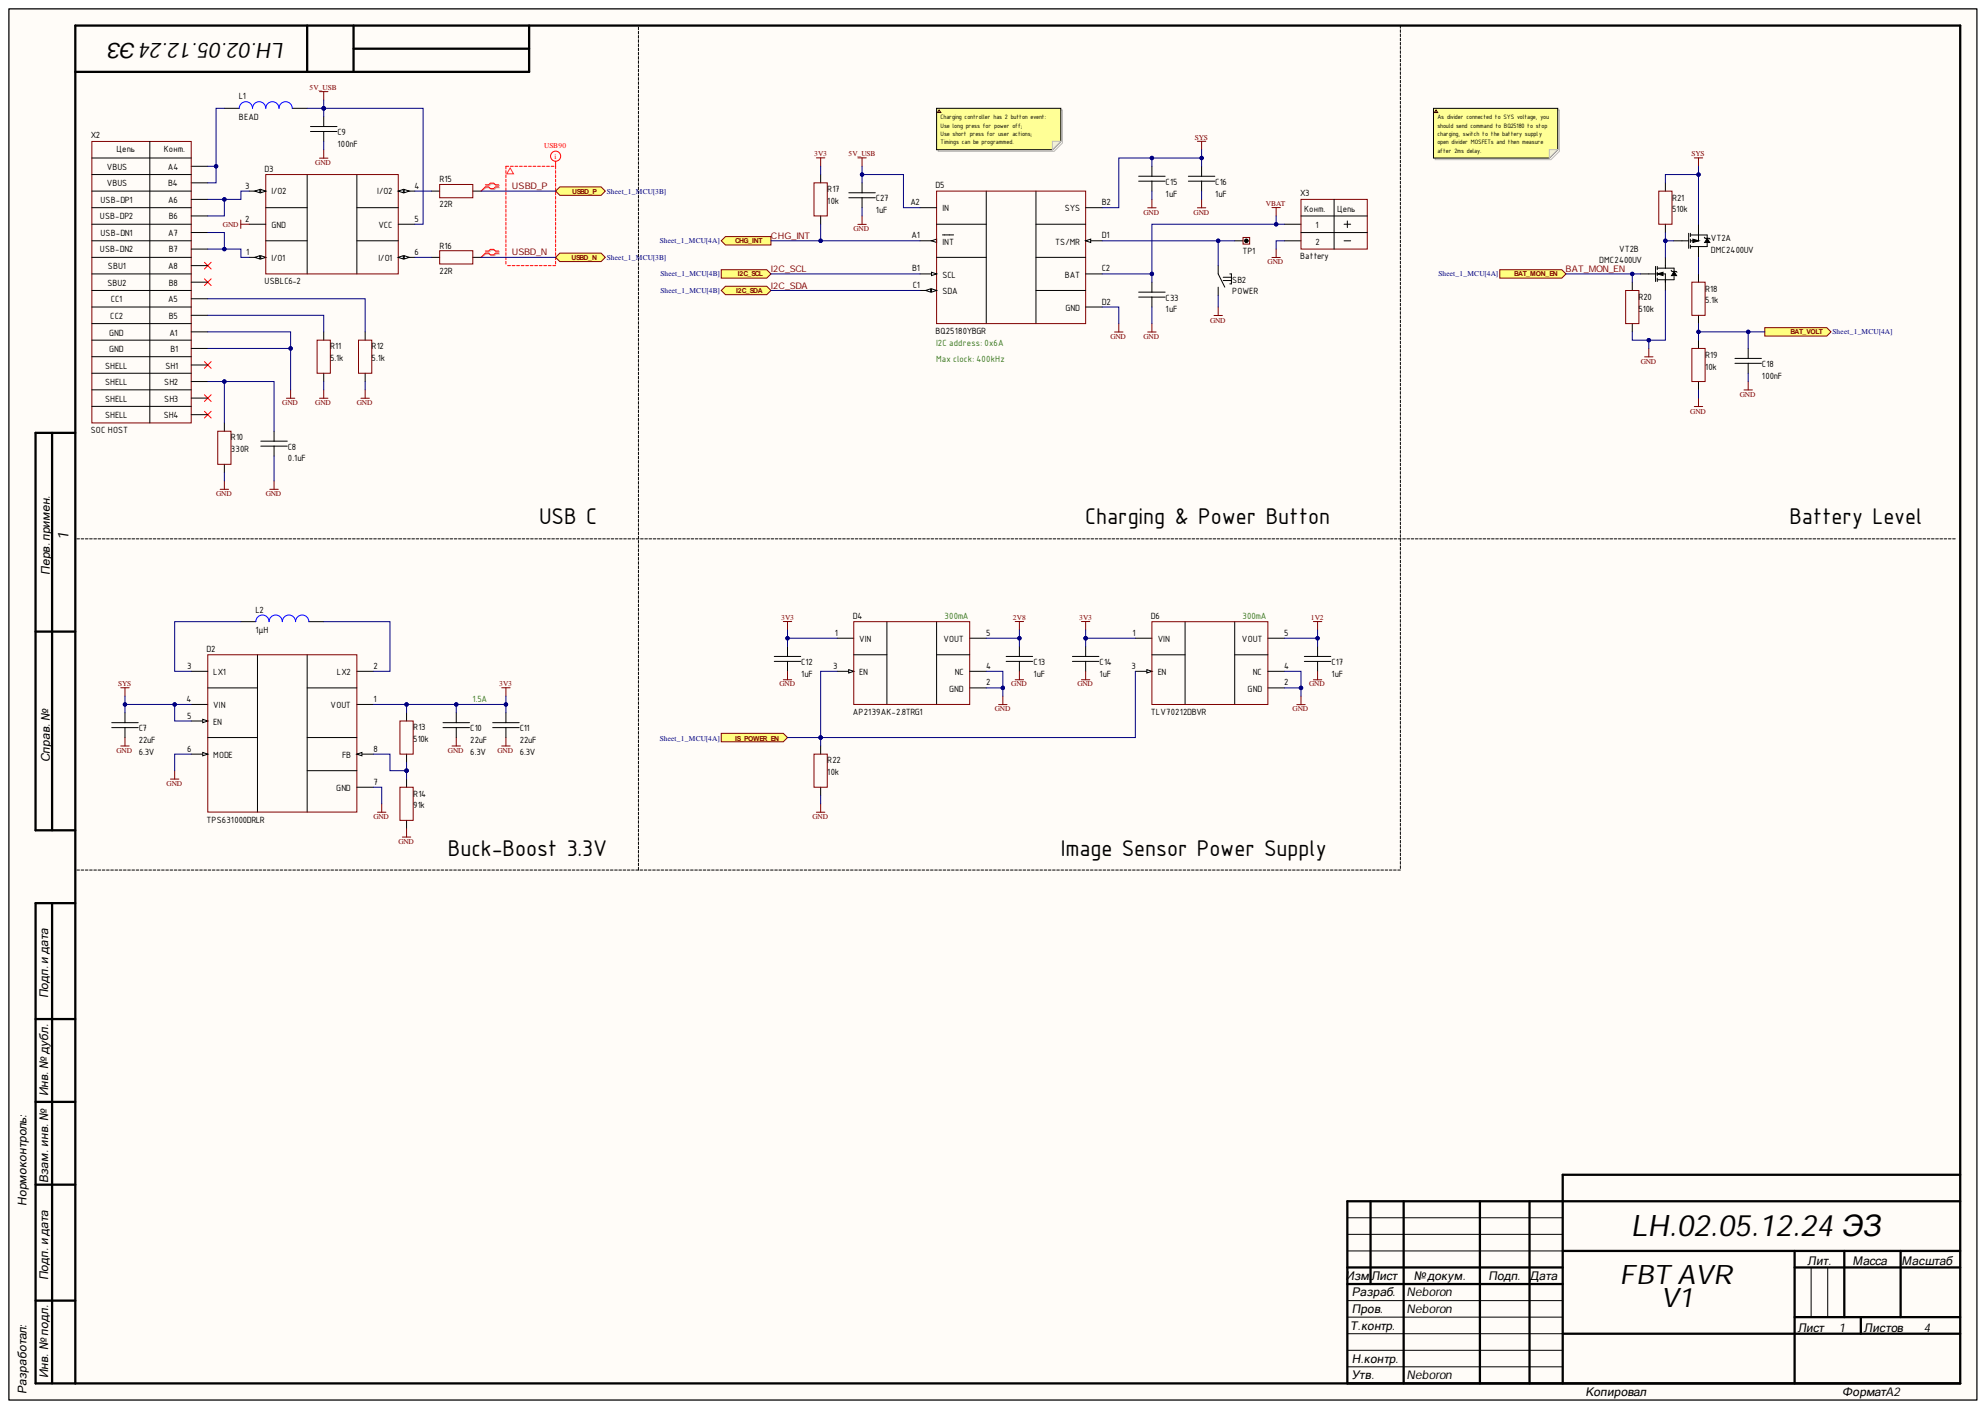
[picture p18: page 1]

Инв. № подл. Инв. № дубл. Подп. и дата Взам. инв. № Подп. и дата Перв. примен. Справ. №

Image Sensor Power Supply

FBT AVR V1 | Лит. | М асса | М а с штаб

Изм. | Лист | № до ку м . | Подп . | Да та
Раз р аб. | | Ne b o ro n
Про в. | | Ne b o ro n
Т. ко нтр. | | | | | Лист 1 | Листов 4

Н . ко н тр.
Ут в . | Ne b o ro n

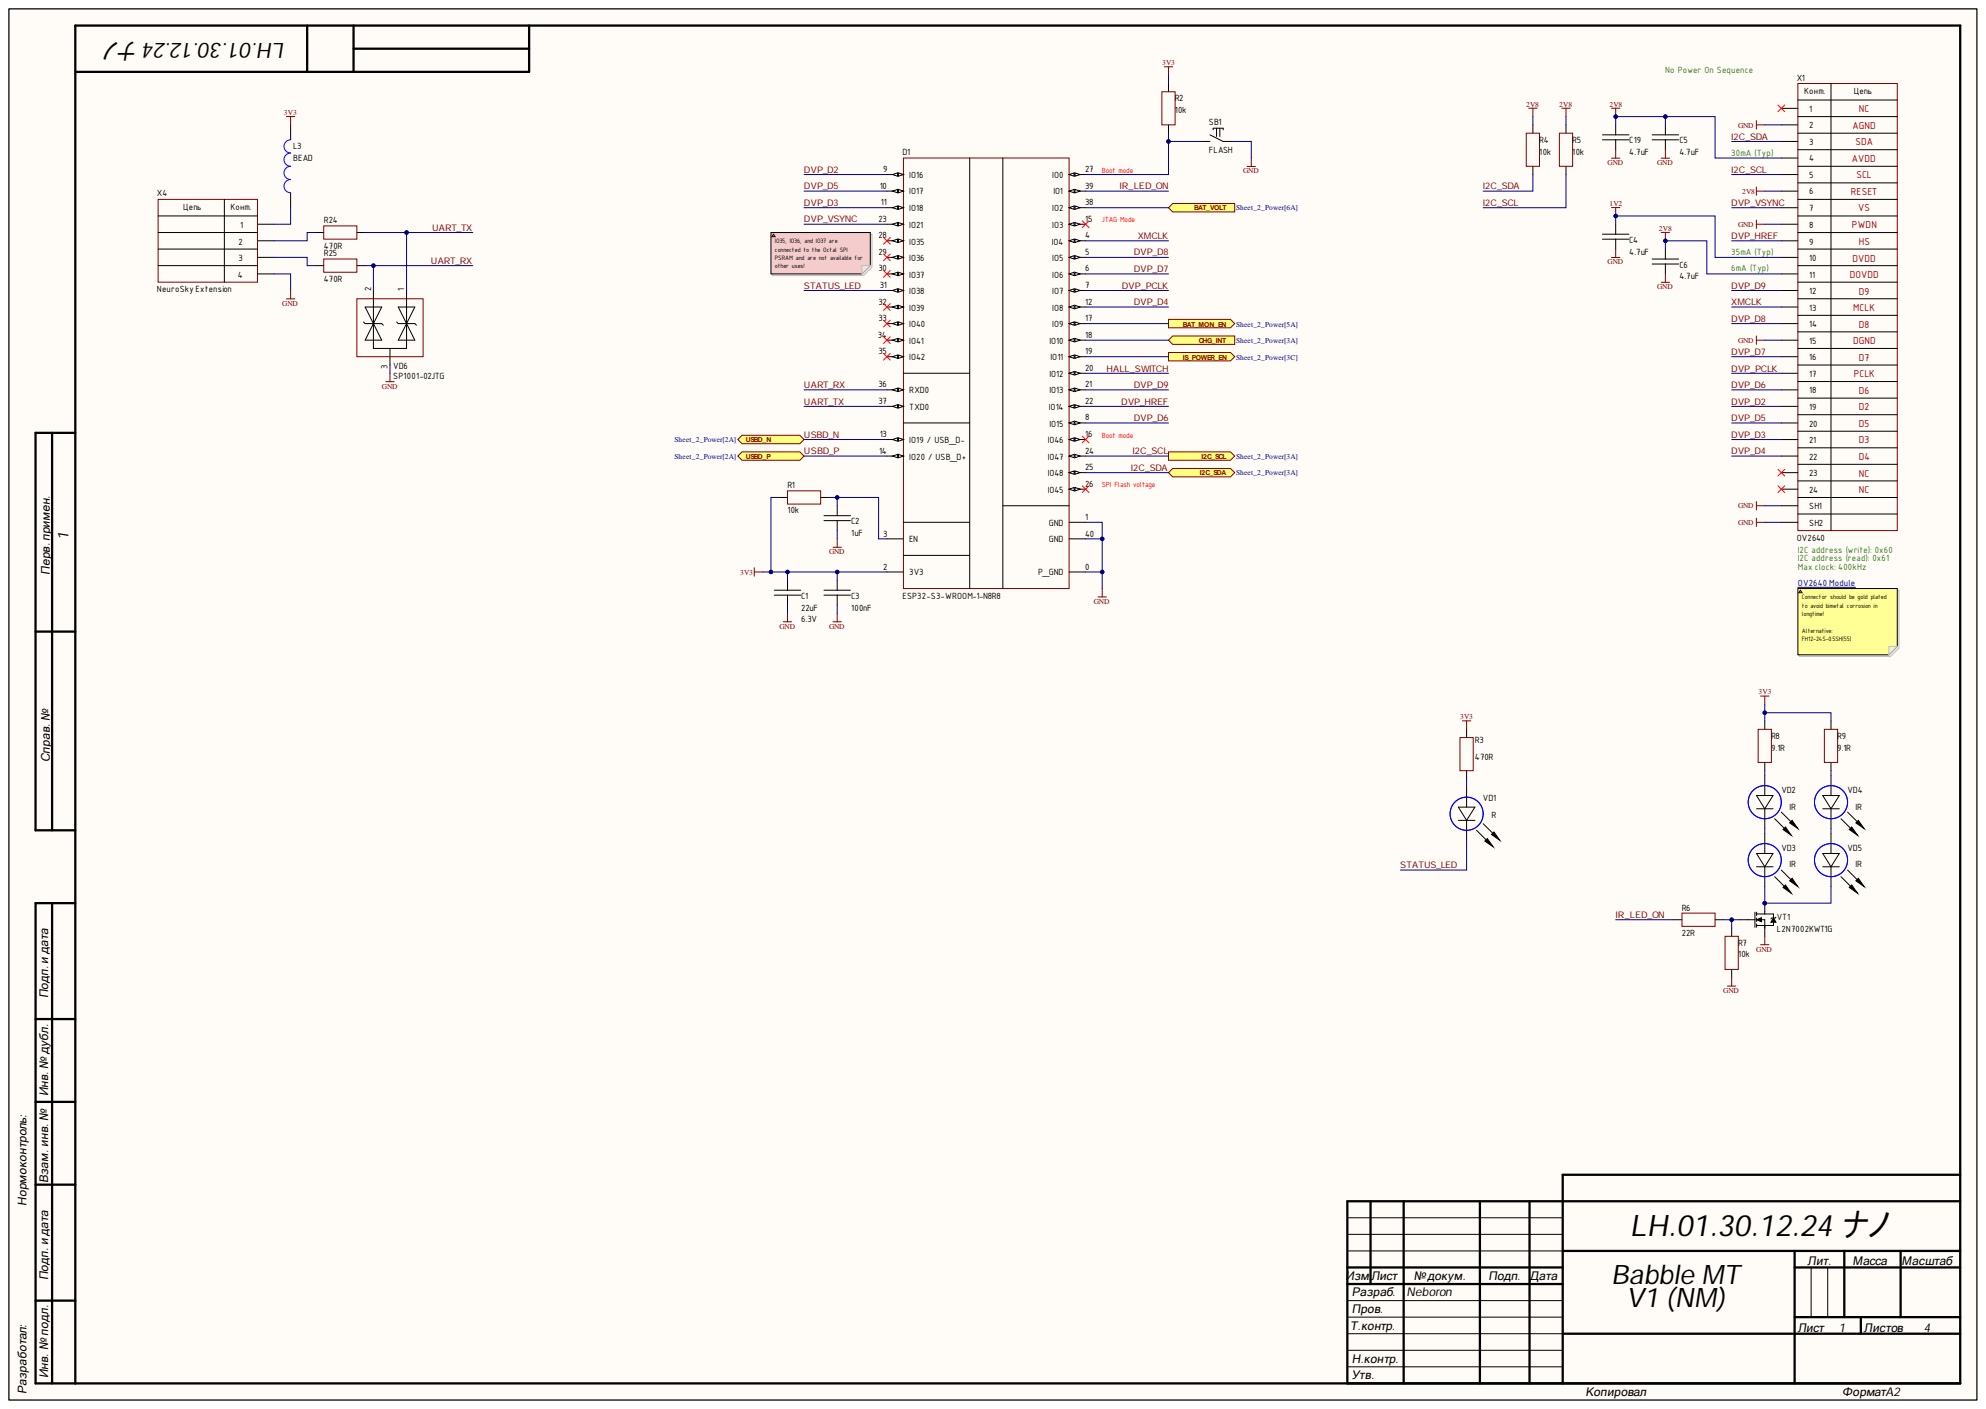
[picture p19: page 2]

X 1
К о н т . | Це п ь

AVD D
S C L

D OVD D

D 9
MC L K

D 2
D 5

Инв. № подл. Инв. № дубл. Подп. и дата Взам. инв. № Подп. и дата Перв. примен. Справ. №

Babble MT V1 (NM) | Лит. | М асса | М а с штаб

Изм. | Лист | № до ку м . | Подп . | Да та
Раз р аб. | | Ne b o ro n
Про в.
Т. ко нтр. | | | | | Лист 1 | Листов 4

Н . ко н тр.
Ут в .
